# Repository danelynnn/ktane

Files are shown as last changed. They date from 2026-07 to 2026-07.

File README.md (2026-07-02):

# ktane

keep talkin and nobody goes poof :D

this is a physical recreation of the... _briefcase_, from KEEP TALKING AND NOBODY \<REDACTED\>. the intention of this project is to be as faithful as possible to the original, so some modules might not be included or otherwise altered so that they can exist within the fabric of reality :]

# gameplay loop

as reality cannot be procedurally generated, and is hence often disappointing, the briefcase must be set up at a designated time before the game is considered "active", where every physical element can be assembled manually.

as such, the briefcase will have the following states:

```
enum Phase {
  SETUP, ACTIVE, SOLVED
};
```

1. setup (if applicable):  
   puzzle is inactive, time is frozen at starting time (e.g. 5:00)  
   modules can be inserted or disconnected  
   modules cannot cause strikes or be completed

2. active:
   puzzle is active, time will start ticking down, and modules can be completed/cause mistakes

3. solved (win/loss):
   puzzle is inactive, time is at 0:00  
   modules should not be connected or disconnected at this time  
   modules cannot cause strikes or be completed

# modules

as the original game is grouped into modules, it'd be an absolute shame not to engineer the recreation as modular, as each physical "module" can roughly correspond to one virtual module.

## generic module implementation

each of these modules will be designed as a standalone ATMega328p (IC from an Arduino R3), as this is a lot more cost-effective than dedicating an entire dev board to a module.

as the modules must stay in sync and send/receive information, they must be connected through communication. we're using a simple 2-wire I<sup>2</sup>C communication bus (for details, see "Communication")

all modules will have four pinouts to connect to a bus, aside from the exposed interfaces needed for the module:

- 5v (red)
- gnd (black)
- scl (white)
- sda (yellow)

further circuit schematics can be found in the `kicad/` folder.

## controller "module"

this isn't an actual module, but it has the same footprint and effectively acts as a normal module, so we're counting it here. this is the designated main hub for all of the briefcase's unique properties, including:

- battery count
- indicators
- serial number
- strikes
- timer

this controller will also include a handful of interactive elements, such as a speaker for sound effects and buttons to configure and advance state.

## wires module (finally, the good stuff)

during setup phase, this module will accept any number of pin connections between the 6 left and 6 right terminals. these connections must be made with custom wires with a resistance representing their colour, as follows:

- yellow: 100 &#937;
- red: 220 &#937;
- blue: 470 &#937;
- black: 680 &#937;
- white: 1k &#937;

once setup phase is complete, the module will commit the final configuration of the wires as the "starting state", and any disconnections will cause either a strike or a completion.

any CONNECTIONS... i mean, idk man don't do that lol

# communication

communication across the puzzle is handled through an I<sup>2</sup>C multi-master (different addresses can choose to initiate communication) bus. currently, there is no plan to implement arbitration, so a simple protocol must be created to prevent crosstalk. the general idea is that for any given "state change" event (e.g. user interacting with a module, module/controller connecting, needy module reactivating), only one address should be initiating communication, though this can include any number or combination of send/receives.

## controller

always on address 8

### possible initiations

- request state from module
- send reset signal to module
- send activate signal to module

## module

allocated 56 addresses, could be between 9-64  
there are 14 total modules, but addresses must be unique, so each module type can assign as one of 4 addresses:

- 9-12: wires
- 13-16: button
- 17-20: keypad
- 21-24: simon says
- 25-28: who's on first
- 29-32: memory
- 33-36: morse code
- 37-40: complicated wires
- 41-44: wire sequences(??)
- 45-48: maze
- 49-52: password
- 53-56: gas
- 57-60: capacitor
- 61-64: knob

### possible initiations

- request data from controller
- send status to controller (-1/255 for "caused strike")

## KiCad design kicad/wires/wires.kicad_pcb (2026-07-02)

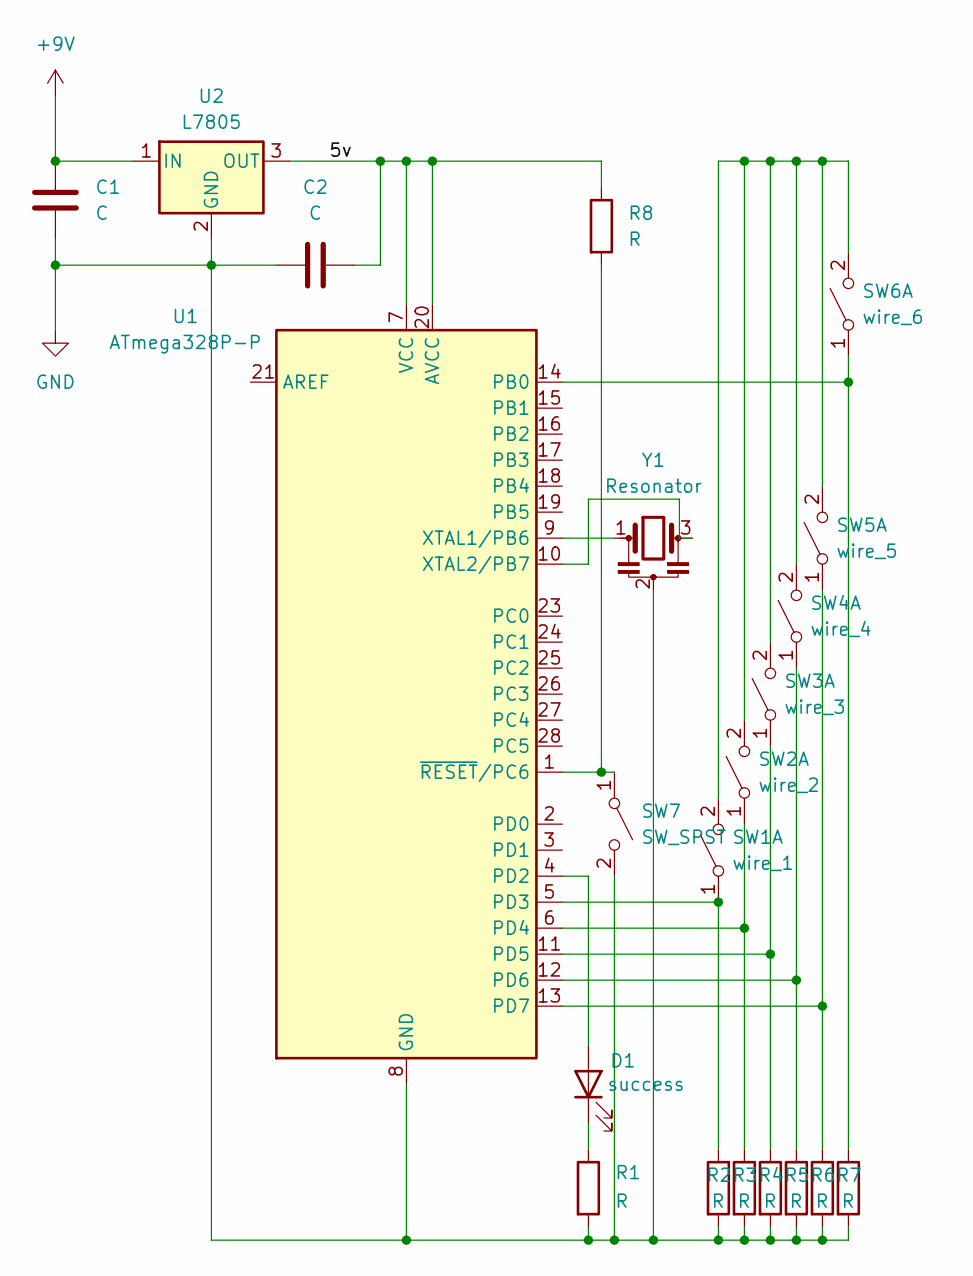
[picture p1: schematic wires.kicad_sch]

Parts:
C1, C2: C; CP_Radial_D5.0mm_P2.50mm
D1: success; LED_D8.0mm
R1, R2, R3, R4, R5, R6, R7, R8: R; R_Axial_DIN0207_L6.3mm_D2.5mm_P10.16mm_Horizontal
SW1: wire_1; SW_DIP_SPSTx01_Slide_6.7x4.1mm_W8.61mm_P2.54mm_LowProfile
SW2: wire_2; SW_DIP_SPSTx01_Slide_6.7x4.1mm_W8.61mm_P2.54mm_LowProfile
SW3: wire_3; SW_DIP_SPSTx01_Slide_6.7x4.1mm_W8.61mm_P2.54mm_LowProfile
SW4: wire_4; SW_DIP_SPSTx01_Slide_6.7x4.1mm_W8.61mm_P2.54mm_LowProfile
SW5: wire_5; SW_DIP_SPSTx01_Slide_6.7x4.1mm_W8.61mm_P2.54mm_LowProfile
SW6: wire_6; SW_DIP_SPSTx01_Slide_6.7x4.1mm_W8.61mm_P2.54mm_LowProfile
SW7: SW_SPST; SW_SPST_TS-1088-xR025
U1: ATmega328P-P; DIP-28_W7.62mm
U2: L7805; TO-220-3_Horizontal_TabDown
Y1: Resonator; Resonator-3Pin_W10.0mm_H5.0mm

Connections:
+9V: C1.1, U2.1 (IN)
/5v: C2.1, R8.1, U1.7 (VCC), U1.20 (AVCC), U2.3 (OUT)
GND: C1.2, C2.2, R1.2, R2.2, R3.2, R4.2, R5.2, R6.2, R7.2, SW7.2 (B), U1.8 (GND), U1.22 (GND), U2.2 (GND), Y1.2
unnamed: D1.2 (A), U1.4 (PD2)
unnamed: D1.1 (K), R1.1
unnamed: R2.1, SW1.1 (A), U1.5 (PD3)
unnamed: SW1.2 (B), SW2.2 (B), SW3.2 (B), SW4.2 (B), SW5.2 (B), SW6.2 (B)
unnamed: R3.1, SW2.1 (A), U1.6 (PD4)
unnamed: R4.1, SW3.1 (A), U1.11 (PD5)
unnamed: R5.1, SW4.1 (A), U1.12 (PD6)
unnamed: R6.1, SW5.1 (A), U1.13 (PD7)
unnamed: R7.1, SW6.1 (A), U1.14 (PB0)
unnamed: R8.2, SW7.1 (A), U1.1 (~RESET/PC6)
unnamed: U1.9 (XTAL1/PB6), Y1.1
unnamed: U1.10 (XTAL2/PB7), Y1.3

Board: 2 copper layers, 21 parts (0 on the bottom side), 15 nets, no tracks yet.

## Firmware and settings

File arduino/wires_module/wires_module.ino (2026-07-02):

// wires module!
// by Allie
//
// contains the functionality for the simple wires module; references a
// controller module for data

#define CONTROLLER_ADDRESS 8
#define I2C_ADDRESS CONTROLLER_ADDRESS + 1 // address 1
#define WIRE_SUCCESS 2
#define WIRE_ONE 3 // Read pin

#include <Wire.h>

enum InputType {
  ACTIVATE,
  SERIALODD,
  SERIALVOWEL,
  BATTERY,
  TIMER,
  STRIKES,
  RESET
};

enum Color { NONE, BLUE, RED, YELLOW, PURPLE, WHITE, BLACK };

enum Phase { SETUP, READY, ACTIVE, SOLVED };

Phase phase = SETUP;
int states[] = {-1, -1, -1, -1, -1, -1};
int answer = -1;

// current game state, this is partially local and partially pulled from
// controller
Color colors[] = {RED, NONE, RED, YELLOW, BLUE, NONE};
bool isSerialOdd = false;

void setup() {
  // put your setup code here, to run once:
  Serial.begin(9600);
  Serial.println();

  // address 1
  Wire.begin(I2C_ADDRESS + 1);
  Wire.onReceive(receiveData);
  Wire.onRequest(sendData);

  pinMode(WIRE_SUCCESS, OUTPUT);
  // set all pins as input
  for (int i = 0; i < 6; i++)
    pinMode(WIRE_ONE + i, INPUT);

  // scan for controller
  Wire.beginTransmission(CONTROLLER_ADDRESS);
  sendData(); // send state to controller
  if (Wire.endTransmission() == 0) {
    // request starting variables from controller
    Wire.requestFrom(CONTROLLER_ADDRESS, 2);
    receiveData(2);
  }

  Serial.println("setup complete:");
  printState();
}

int readout[] = {0, 0, 0, 0, 0, 0};
int debounce[] = {0, 0, 0, 0, 0, 0};

void loop() {
  for (int i = 0; i < 6; i++)
    readout[i] = digitalRead(WIRE_ONE + i);

  for (int i = 0; i < 6; i++) {
    if (readout[i] != states[i]) {
      debounce[i]++;
      if (debounce[i] == 10000) {
        setPin(i, readout[i]);
        debounce[i] = 0;
      }
    } else {
      debounce[i] = 0;
    }
  }
}

void receiveData(int bytes) {
  InputType signal = Wire.read();
  int data = Wire.read();

  Serial.print("received data, type ");
  Serial.print(signal);
  Serial.print(" data ");
  Serial.println(data);

  switch (signal) {
  case ACTIVATE:
    phase = ACTIVE;
    answer = handleRules(colors);
    printState();
    break;
  case SERIALODD:
    isSerialOdd = data;
    answer = handleRules(colors);
    break;
  case RESET:
    phase = SETUP;
    update(-1);
    break;
  }
}

void sendData() {
  Serial.print("sending from ");
  Serial.print(I2C_ADDRESS);
  Wire.write(I2C_ADDRESS);
  Serial.print(" data ");
  Serial.println(phase);
  Wire.write(phase);
}

// returns whether should report to controller
bool update(int pin) {
  bool shouldReport = false;

  if (phase == SETUP) {
    bool ready = true;
    for (int i = 0; i < 6; i++) {
      if ((colors[i] != NONE && states[i] == 1) ||
          (colors[i] == NONE && states[i] == 0)) {
      } else {
        ready = false;
      }
    }

    if (ready) {
      phase = READY;
      shouldReport = true;
    }
  } else if (phase == READY || phase == ACTIVE) {
    if (pin == answer) {
      phase = SOLVED;
      shouldReport = true;
    } else {
      Serial.println("mistake");

      Wire.beginTransmission(8);
      Wire.write(9);
      Wire.write(-1);
      Wire.endTransmission();
    }
  }

  if (phase == SOLVED) {
    digitalWrite(WIRE_SUCCESS, true);
  } else {
    digitalWrite(WIRE_SUCCESS, false);
  }
  printState();

  return shouldReport;
}

void setPin(int pin, int state) {
  states[pin] = state;

  Serial.print("pin ");
  Serial.print(pin);
  Serial.print(" has been set to ");
  Serial.print(state);
  Serial.println();

  if (update(pin)) {
    Wire.beginTransmission(8);
    sendData();
    Wire.endTransmission();
  }
}

int handleRules(Color colors[]) {
  int connectedWires[6]; // list of connected *indices*
  int numWires = 0;

  for (int i = 0; i < 6; i++) {
    if (colors[i] != NONE) {
      connectedWires[numWires++] = i;
    }
  }

  switch (numWires) {
  case 3:
    if (countWires(RED) == 0) {
      return connectedWires[1];
    } else if (colors[connectedWires[numWires - 1]] == WHITE) {
      return connectedWires[numWires - 1];
    } else if (countWires(BLUE) > 1) {
      // last blue wire
      for (int i = numWires - 1; i >= 0; i--) {
        if (colors[connectedWires[i]] == BLUE) {
          return connectedWires[i];
        }
      }
    } else {
      return connectedWires[numWires - 1];
    }
    break;
  case 4:
    if (countWires(RED) > 1 && isSerialOdd) {
      // last red wire
      for (int i = numWires - 1; i >= 0; i--) {
        if (colors[connectedWires[i]] == RED) {
          return connectedWires[i];
        }
      }
    } else if (colors[connectedWires[numWires - 1]] == YELLOW &&
               countWires(RED) == 0) {
      return connectedWires[0];
    } else if (countWires(BLUE) == 1) {
      return connectedWires[0];
    } else if (countWires(YELLOW) > 1) {
      return connectedWires[numWires - 1];
    } else {
      return connectedWires[1];
    }
    break;
  case 5:
    if (colors[connectedWires[numWires - 1]] == BLACK && isSerialOdd) {
      return connectedWires[3];
    } else if (countWires(RED) == 1 && countWires(YELLOW) > 1) {
      return connectedWires[0];
    } else if (countWires(BLACK) == 0) {
      return connectedWires[1];
    } else {
      return connectedWires[0];
    }
    break;
  case 6:
    if (countWires(YELLOW) == 0 && isSerialOdd) {
      return connectedWires[2];
    } else if (countWires(YELLOW) == 1 && countWires[WHITE] > 1) {
      return connectedWires[3];
    } else if (countWires(RED) == 0) {
      return connectedWires[numWires - 1];
    } else {
      return connectedWires[3];
    }
    break;
  }
}

int countWires(Color color) {
  int count = 0;

  for (int i = 0; i < 6; i++) {
    if (colors[i] == color)
      count++;
  }

  return count;
}

void printArray(int arr[], int len) {
  Serial.print("[");
  for (int i = 0; i < len; i++) {
    Serial.print(arr[i]);
    Serial.print(" ");
  }
  Serial.print("]");
}

void printState() {
  Serial.print("we are in phase ");
  Serial.print(phase);
  Serial.print(", current state is ");
  printArray(states, 6);

  if (phase == ACTIVE) {
    Serial.print(", correct answer is ");
    Serial.print(answer);
  }

  Serial.println();
}

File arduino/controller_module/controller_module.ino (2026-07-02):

// controller module!
// by Allie
//
// contains "heart" of the module, mostly just info:
// serial number, batteries, current timer, number of strikes

#define I2C_ADDRESS 8

#include <Wire.h>

enum OutputType {
  ACTIVATE,
  SERIALODD,
  SERIALVOWEL,
  BATTERY,
  TIMER,
  STRIKES,
  RESET
};

enum Phase { SETUP, READY, ACTIVE, SOLVED };

char serial[] = "DL5QF3";
int batteries = 3;
int strikes = 0;

int numModules = 0;
int addresses[12];
int states[12];

bool bombStatus = false;

void setup() {
  // put your setup code here, to run once:
  Serial.begin(9600);
  Serial.println();

  // address 0
  Wire.begin(I2C_ADDRESS);
  Wire.onReceive(receiveData);
  Wire.onRequest(sendData);

  // scan addresses for connected modules
  for (int i = 1; i <= 56; i++) {
    Wire.beginTransmission(I2C_ADDRESS + i);
    Wire.write(RESET);
    if (Wire.endTransmission() == 0) {
      // request state from module
      Wire.requestFrom(I2C_ADDRESS + i, 2);
      receiveData(2);

      // send starting variables to module
      Wire.beginTransmission(I2C_ADDRESS + i);
      Wire.write(SERIALODD);
      Wire.write(createPacket(SERIALODD));
      Wire.endTransmission();
    }
  }

  Serial.println("setup complete:");
  printState();
}

void loop() {
  // put your main code here, to run repeatedly:

  // Wire.requestFrom(4, 16);
  // while (Wire.available()) { // peripheral may send less than requested
  //   char c = Wire.read(); // receive a byte as character
  //   Serial.print(c);         // print the character
  // }
  delay(1000);
}

void receiveData(int bytes) {
  int index = getModuleIndex(Wire.read());
  int data = Wire.read();

  Serial.print("signal from module ");
  Serial.print(index);
  Serial.print(" data ");
  Serial.println(data);

  if (data == 255) // module sent -1, strike made
    strikes++;
  else // module sent status
    states[index] = data;

  bool solved = true;
  for (int i = 0; i < numModules; i++) {
    if (states[i] != SOLVED)
      solved = false;
  }
  if (solved)
    bombStatus = true;
  else
    bombStatus = false;

  printState();
}

void sendData() {
  Serial.print("sending type ");
  Serial.print(SERIALODD);
  Wire.write(SERIALODD);
  Serial.print(" data ");
  Serial.println(createPacket(SERIALODD));
  Wire.write(createPacket(SERIALODD));
}

void tryStart() {
  bool ready = true;

  for (int i = 0; i < numModules; i++)
    if (states[i] != READY)
      ready = false;

  // if ready, activate all modules
  if (ready) {
    for (int i = 0; i < numModules; i++) {
      Serial.print("activating ");
      Serial.println(I2C_ADDRESS + addresses[i]);

      Wire.beginTransmission(I2C_ADDRESS + addresses[i]);
      Wire.write(RESET);
      Wire.endTransmission();
    }
  }
}

int getModuleIndex(int address) {
  int index = -1;
  for (int i = 0; i < numModules; i++) {
    if (address == addresses[i]) {
      index = i;
      break;
    }
  }

  if (index == -1) {
    addresses[numModules] = address;
    return numModules++;
  } else {
    return index;
  }
}

bool isSerialOdd() { return (serial[5] - '0') % 2 == 1; }

bool hasSerialVowel() {
  for (int i = 0; i < 6; i++) {
    if (serial[i] == 'A' || serial[i] == 'E' || serial[i] == 'I' ||
        serial[i] == 'O' || serial[i] == 'U')
      return true;
  }

  return false;
}

byte createPacket(OutputType type) {
  byte data;

  switch (type) {
  case SERIALODD:
    data = isSerialOdd();
    break;
  case SERIALVOWEL:
    data = hasSerialVowel();
    break;
  case BATTERY:
    data = batteries ? batteries < 4 : 4;
    break;
  case TIMER:
    // timer i can't be fucked
    break;
  case STRIKES:
    data = strikes;
    break;
  default:
    break;
  }

  return data;
}

void printArray(int arr[], int len) {
  for (int i = 0; i < len; i++) {
    Serial.print(arr[i]);
    Serial.print(" ");
  }
}

void printState() {
  Serial.print("module states: ");
  printArray(states, numModules);
  Serial.print(", strikes: ");
  Serial.print(strikes);
  Serial.print(", remaining time: ");
  Serial.print(", bomb is ");
  Serial.println(bombStatus ? "SOLVED" : "pending");
}

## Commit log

2024-12-10 MODULE LOGIC IS COMPLETE (with a success pin)
2024-12-10 organised wires & file structure
2024-12-10 blinky circuit is alive
2024-12-12 fixed problem with timer because the start variable i was using to determine the start of the color cycle was an int and that fucked up math woo
    [simon_module.ino]
2024-12-12 reset phase and added layout photo
    [simon_module.ino]
2026-07-02 docs been moved to the readme!!! (also some schematics, still wip)
    [analog_test.kicad_pcb, analog_test.kicad_sch, wires.kicad_pcb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]
